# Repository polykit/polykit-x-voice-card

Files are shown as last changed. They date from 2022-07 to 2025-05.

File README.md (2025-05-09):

# Polykit-X Voice Card

This repository contains schematics and Kicad PCB layout for a voice card with pole-mixing multimode filter. Multiple cards like this are typically used in a polyphonic synthesizer. It can also be used in a monophonic setup. There is only minimal additional circuitry like some pots, input jacks and voltage regulators needed.

Voice card specs:

- Single oscillator with saw, triangle and pulse output
- Multiple VCAs to blend between different input signals, a main VCA for the envelope and a panning VCA for stereo output
- An additional external input that can be mixed in, eg. a noise signal
- One envelope generator for the VCA. It can modulate filter frequency and resonance, also with an inverted signal
- A pole-mixing multimode filter with 8 filter responses:
    - 4P LP
    - 2P LP
    - 4P HP
    - 2P HP
    - 4P BP
    - 2P BP
    - 3P AP + 1P LP
    - 4P N
- There are multiple options two switch and blend between different signals and filter responses
- PWM, FM and synchronization inputs

Video playlist on its functionality and design process: https://www.youtube.com/watch?v=2grRbG7IwDw&list=PLUKLEU8jmlbHH4_13YZM0MI6ez4gYQPfy

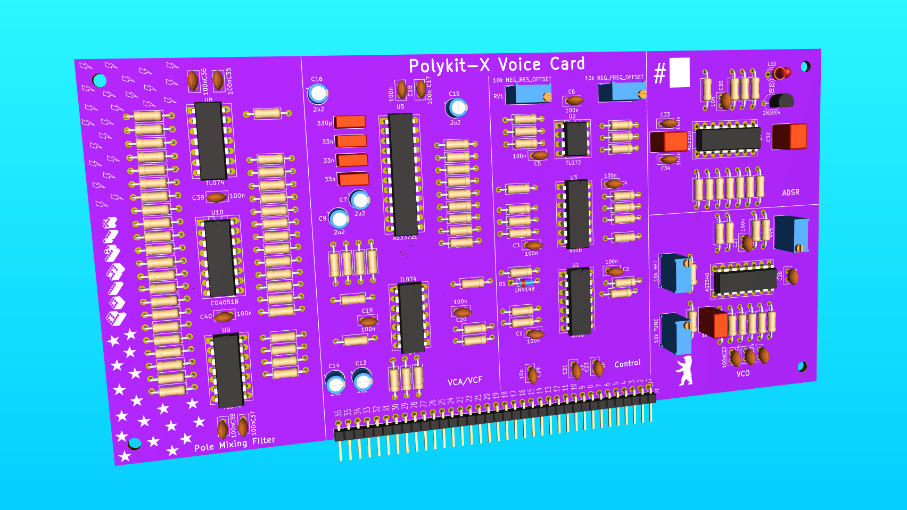
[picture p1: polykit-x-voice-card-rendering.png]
Polykit-X Voice Card Rendering


## Printed Circuit Boards

Geber files for PCB production [can be downloaded here](plots/).

## Pinout

| Pin # | Description | Short | Voltage Range | Type | Direction | Note |
|---|---|---|---|---|---|---|
| 1 | Ground | GND | | | |
| 2 | +12V | +12V | | | |
| 3 | -12V | -12V | | | |
| 4 | +5V | +5V | | | |
| 5 | -5V | -5V | | | |
| 6 | Pitch control | PITCH | ±5V | CV | | 1
| 7 | PWM | PWM | 0V to 5V | CV | |
| 8 | FM | FM | | Signal | |
| 9 | Soft sync | SSYNC | | Signal | |
| 10 | Hard sync | HSYNC | | Signal | |
| 11 | Envelope Attack | ADSR_A | 0V to -5V | CV | |
| 12 | Envelope Decay | ADSR_D | 0V to -5V | CV | |
| 13 | Envelope Sustain | ADSR_S | 0V to 5V | CV | |
| 14 | Envelope Release | ADSR_R | 0V to -5V | CV | |
| 15 | Envelope Trigger | TRIG | 0V/5V | Trig | |
| 16 | Envelope Gate | GATE | 0V/5V | Gate | |
| 17 | Envelope Output | ADSR_OUT | 0V to 5V | CV | |
| 18 | Enable saw signal | SAW_ON | 0V/5V | Switch | |
| 19 | Enable triangle sig. | TRIANGLE_ON | 0V/5V | Switch | |
| 20 | Enable ext. signal | EXTERNAL_ON | 0V/5V | Switch | |
| 21 | Neg. freq. by ADSR | FREQ_ADSR_NEQ | 0V/5V | Switch | |
| 22 | Freq. by ADSR | FREQ_ADSR | 0V/5V | Switch | |
| 23 | Res. by ADSR | RES_ADSR | 0V/5V | Switch | |
| 24 | Neg. res. by ADSR | REF_ADSR_NEQ  | 0V/5V | Switch | |
| 25 | Input level 1 | LVL1 | 0V to 5V | CV | |
| 26 | Input level 2 | LVL2 | 0V to 5V | CV | |
| 27 | VCA | VCA_CV | 0V to 5V | CV | |
| 28 | Output panning | PAN_CV | -2V to 2V | CV | |
| 29 | External input | EXTERNAL_IN | | Signal | |
| 30 | Freq. control | FREQ_CV | 0V to 5V | CV | |
| 31 | Res. control | RES_CV | 0V to 5V | CV | |
| 32 | Filter mode A | FILTER_MODE_A | 0V/5V | Switch | |
| 33 | Filter mode B | FILTER_MODE_B | 0V/5V | Switch | |
| 34 | Filter mode C | FILTER_MODE_C | 0V/5V | Switch | |
| 35 | Output left | OUT_L | | Signal | | 2
| 36 | Output right | OUT_R | | Signal | | 2

Note 1: A 100k ohm resistor on pitch CV input is needed. Multiple CV sources can be added by using multiple resistors in parallel

Note 2: Max. output volume can be adjusted by changing R32/R33

## Filter modes

| # | C B A | Filter response |
|---|---|---|
| 0 | 0 0 0 | 4P LP |
| 1 | 0 0 1 | 2P LP |
| 2 | 0 1 0 | 4P HP |
| 3 | 0 1 1 | 2P HP |
| 4 | 1 0 0 | 4P BP |
| 5 | 1 0 1 | 2P BP |
| 6 | 1 1 0 | 3P AP + 1P LP |
| 7 | 1 1 1 | 4P N |

Select filter mode on pins 32-34

0=GND, 1=5V

## Tuning Procedure

### VCO

You need a control voltage 1V/octave source like a keyboard or two fixed, precise voltages in order to tune the VCO. Also a tuning device or a mobile tuning app is needed.

RV3 (TUNE) is for trimming the overall tune, RV5 (SCALE) is for adjusting the distance between two notes.

Take two notes that are one octave apart, eg. C3 and C4. play the first note and trim RV3 to that note.

Now go back and forth between both notes and adjust RV5 so that the correct distance between them gets closer. The first note will drift away while doing this so go back to it by adjusting RV3 again from time to time. Repeat this until both notes are perfectly in tune.

RV4 (HFT) is for trimming the higher frequencies if neccessary.

## BOM

|Reference |Qnty|Value |Description |
|---|----|---|---|
|C1, C2, C3, C4, C5, C6, C17, C18, C19, C20, C22, C27, C28, C33, C34, C35, C36, C37, C38, C39, C40 |21  |100n |Unpolarized capacitor |
|C7, C9, C13, C14, C15, C16 |6 |2,2uF |Polarized capacitor |
|C8, |1 |330p |Unpolarized capacitor, film or mylar |
|C10, C11, C12 |3 |33n |Unpolarized capacitor, film or mylar |
|C21, C23 |2 |1n |Unpolarized capacitor |
|C24, C25, C29, C30 |4 |10n |Unpolarized capacitor |
|C26 |1 |1n* |Unpolarized capacitor, *polypropylene or similar |
|C31 |1 |10n* |Unpolarized capacitor, *polypropylene or similar |
|C32 |1 |33n* |Unpolarized capacitor, *polypropylene or similar |
|D1 |1 |1N4148 |100V 0.15A standard switching diode, DO-35 |
|D2 |1 |LED |3mm |
|J1 |1 |Conn_01x36 | Pin header 2.54mm 1x36pin 90 degree angle
|Q1 |1 |2N3904 | NPN Transistor, TO-92 |
|R1, R3, R4, R43, R44 |5 |1M |Resistor |
|R2, R28, R29, R38, R42 |4 |470k |Resistor |
|R5, R6, R7, R21, R22, R24, R25, R54, R55, R56, R60, R63, R68, R73, R74, R75, R76, R93, R101, R102, R103 |21  |10k |Resistor |
|R8, R9, R10, R11, R12, R13, R14, R15, R18, R19, R20, R69, R70, R71 |14  |100k |Resistor |
|R16, R17, R23 |3 |20k |Resistor |
|R26, R27, R41, R72 |4 |68k |Resistor |
|R30, R31, R34, R35, R37, R64, R65, R66, R67 |9 |1k |Resistor |
|R32, R33, R36, R62 |4 |33k |Resistor |
|R39, R40 |2 |22k |Resistor |
|R45 |1 |330k |Resistor |
|R46 |1 |1M5 |Resistor |
|R47, R48, R57, R58, R59 |5 |470 |Resistor |
|R49 |1 |24k |Resistor |
|R50 |1 |5k6 |Resistor |
|R51 |1 |1k8 |Resistor |
|R52 |1 |10M |Resistor |
|R53 |1 |47k |Resistor |
|R61 |1 |680 |Resistor |
|R77, R79, R80, R81, R82, R86, R87, R89, R90, R91, R92, R96 |12  |30k |Resistor |
|R78, R88, R97, R98, R99, R100 |6 |15k |Resistor |
|R83, R85, R95 |3 |7k5 |Resistor |
|R84, R94 |2 |4k99 |Resistor |
|R104 |1 |4k7 |Resistor |
|RV1 |1 |10k NEG_RES_OFFSET |Trim-potentiometer |
|RV2 |1 |10k NEG_FREQ_OFFSET|Trim-potentiometer |
|RV3 |1 |10k TUNE |Trim-potentiometer |
|RV4 |1 |10k HFT |Trim-potentiometer |
|RV5 |1 |10k SCALE |Trim-potentiometer |
|U1, U3 |2 |4016 |Quad Analog Switches |
|U2 |1 |TL072 |Dual Low-Noise JFET-Input Operational Amplifiers, DIP-8/SOIC-8 |
|U4, U8, U9 |3 |TL074 |Quad Low-Noise JFET-Input Operational Amplifiers, DIP-14/SOIC-14 |
|U5 |1 |AS3372E |4-pole VCF, dual channel input mixer, VCA, panning VCA |
|U6 |1 |AS3340 |Voltage Controlled Oscillator (VCO), DIP-16/SOIC-16 |
|U7 |1 |AS3310 |ADSR Voltage Controlled Envelope Generator, DIP-16/SOIC-16 |
|U10 |1 |CD4051B |CMOS single 8-channel analog multiplexer demultiplexer, TSSOP-16/DIP-16/SOIC-16 |

## References

Article on Pole Mixing Filters: https://electricdruid.net/multimode-filters-part-2-pole-mixing-filters

Oberheim Matrix-12 Service Manual: https://archive.org/details/oberheim_MATRIX-12_SERVICE_MANUAL

Oberheim Xpander Service Manual: https://archive.org/details/oberheim_XPANDER_SERVICE_MANUAL

Sequential Prophet T8 Service Manual: https://archive.org/details/sm_SCI_T8_Service_Manual_Complete_sm

AS3372E Datasheet: https://www.ericasynths.lv/media/AS3372E.pdf

AS3310 Datasheet: https://www.alfarzpp.lv/eng/sc/AS3310.pdf

AS3340 Datasheet: https://www.alfarzpp.lv/eng/sc/AS3340.pdf

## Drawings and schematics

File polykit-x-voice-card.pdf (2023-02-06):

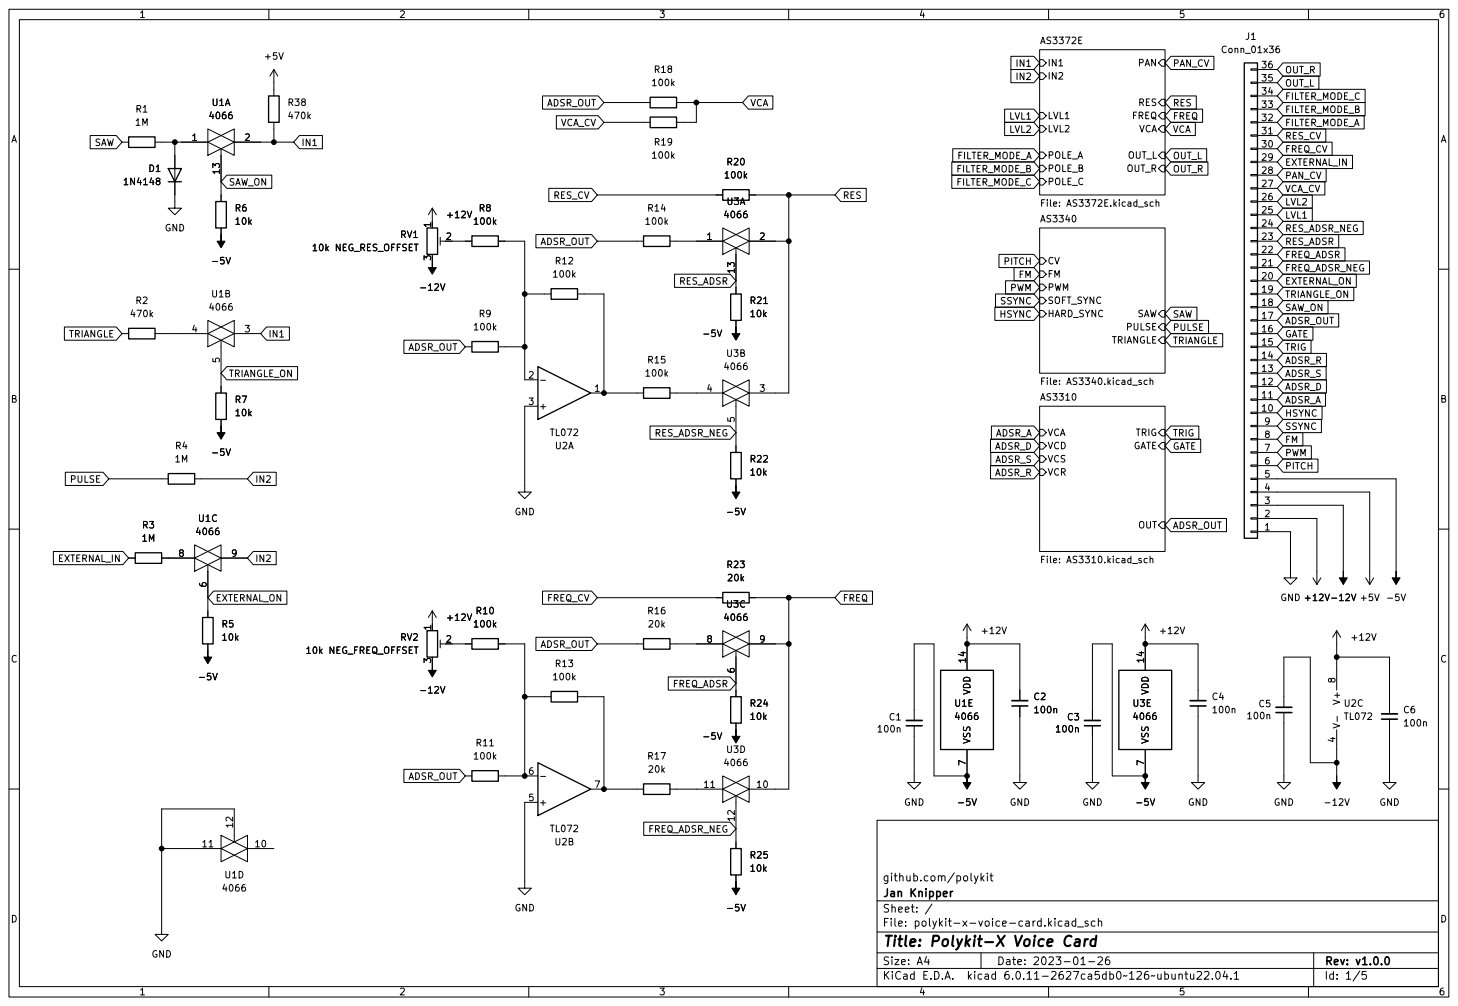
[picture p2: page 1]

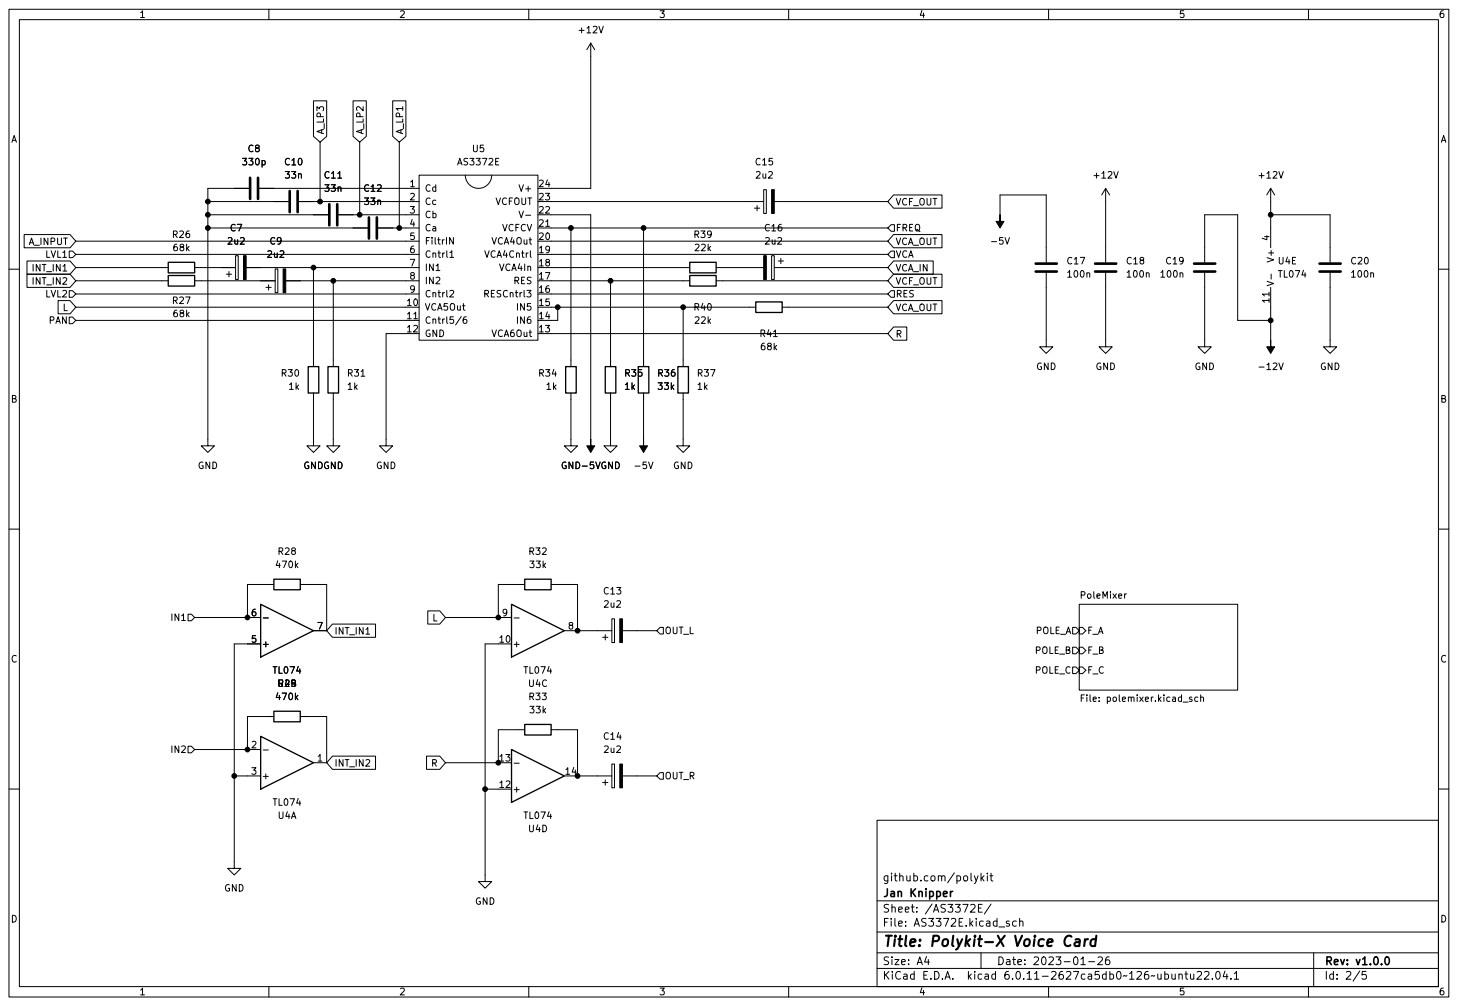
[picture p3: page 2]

PoleMixer File: polemixer.kicad_sch GND

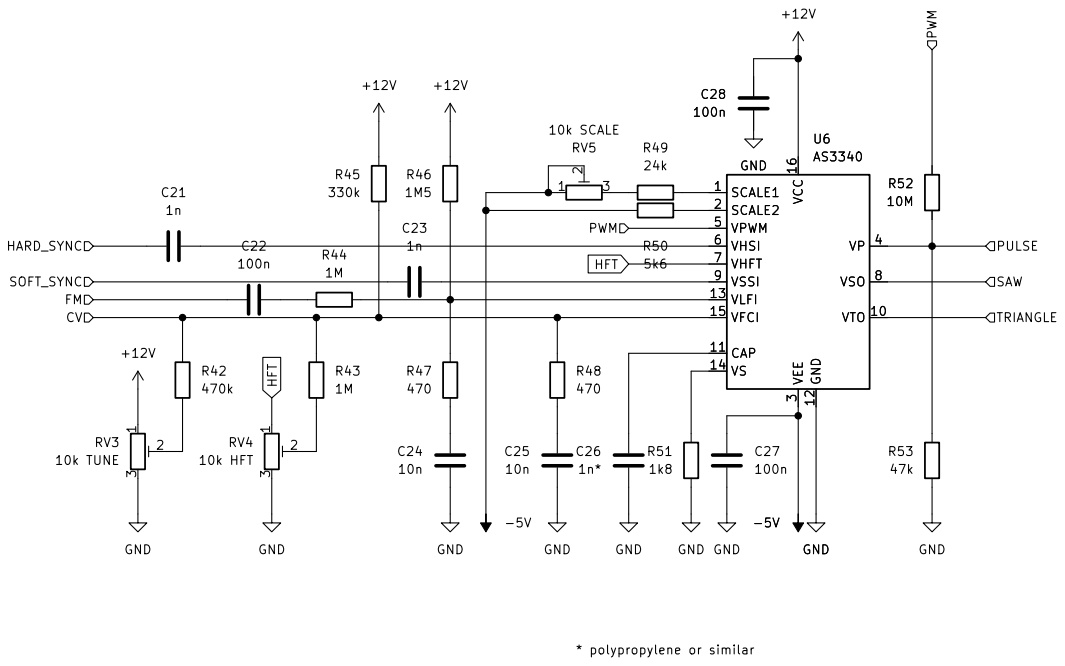
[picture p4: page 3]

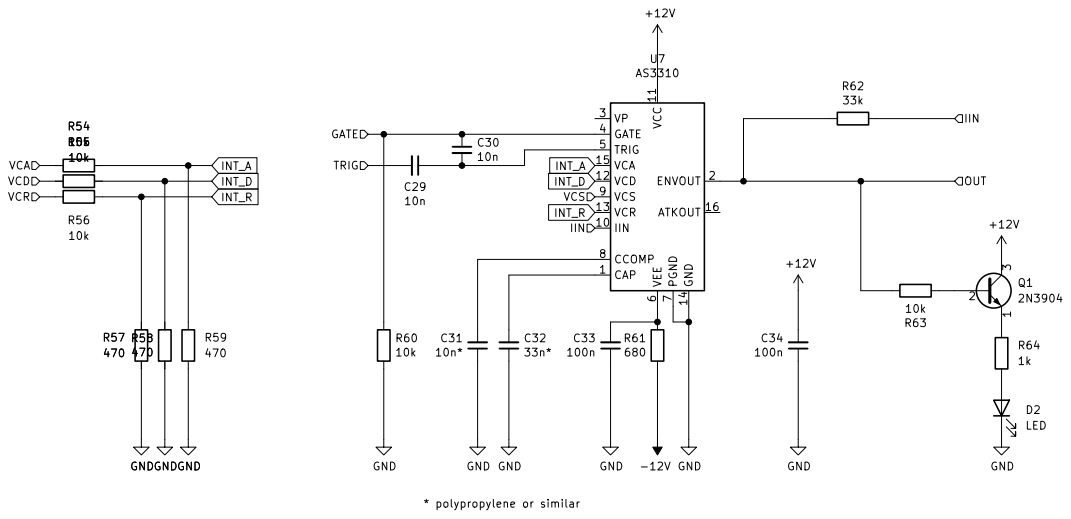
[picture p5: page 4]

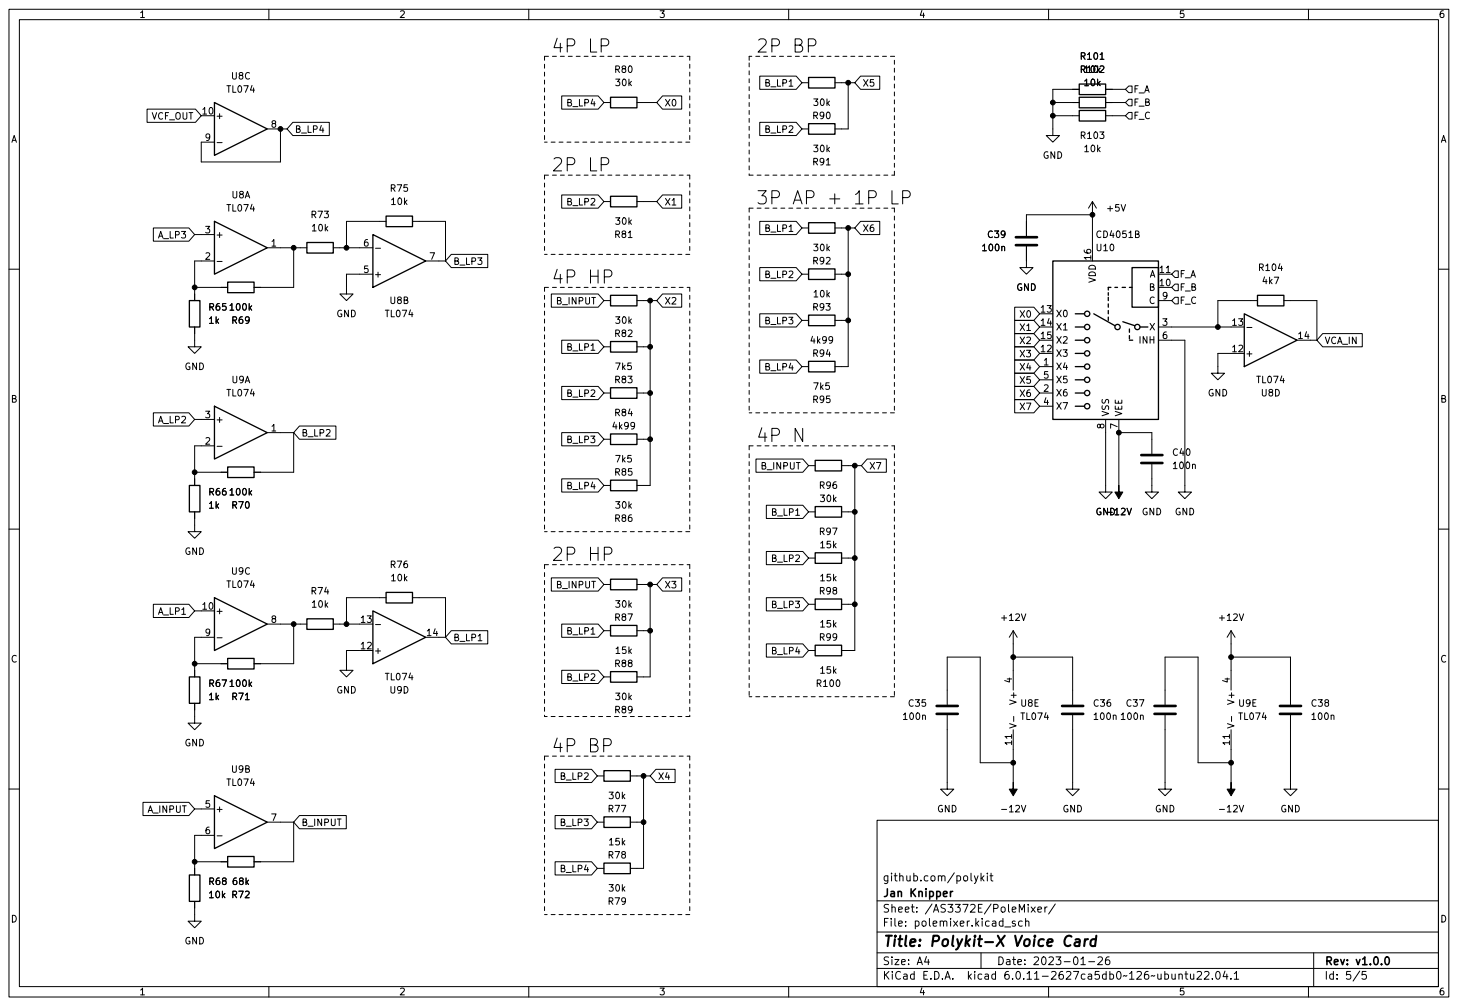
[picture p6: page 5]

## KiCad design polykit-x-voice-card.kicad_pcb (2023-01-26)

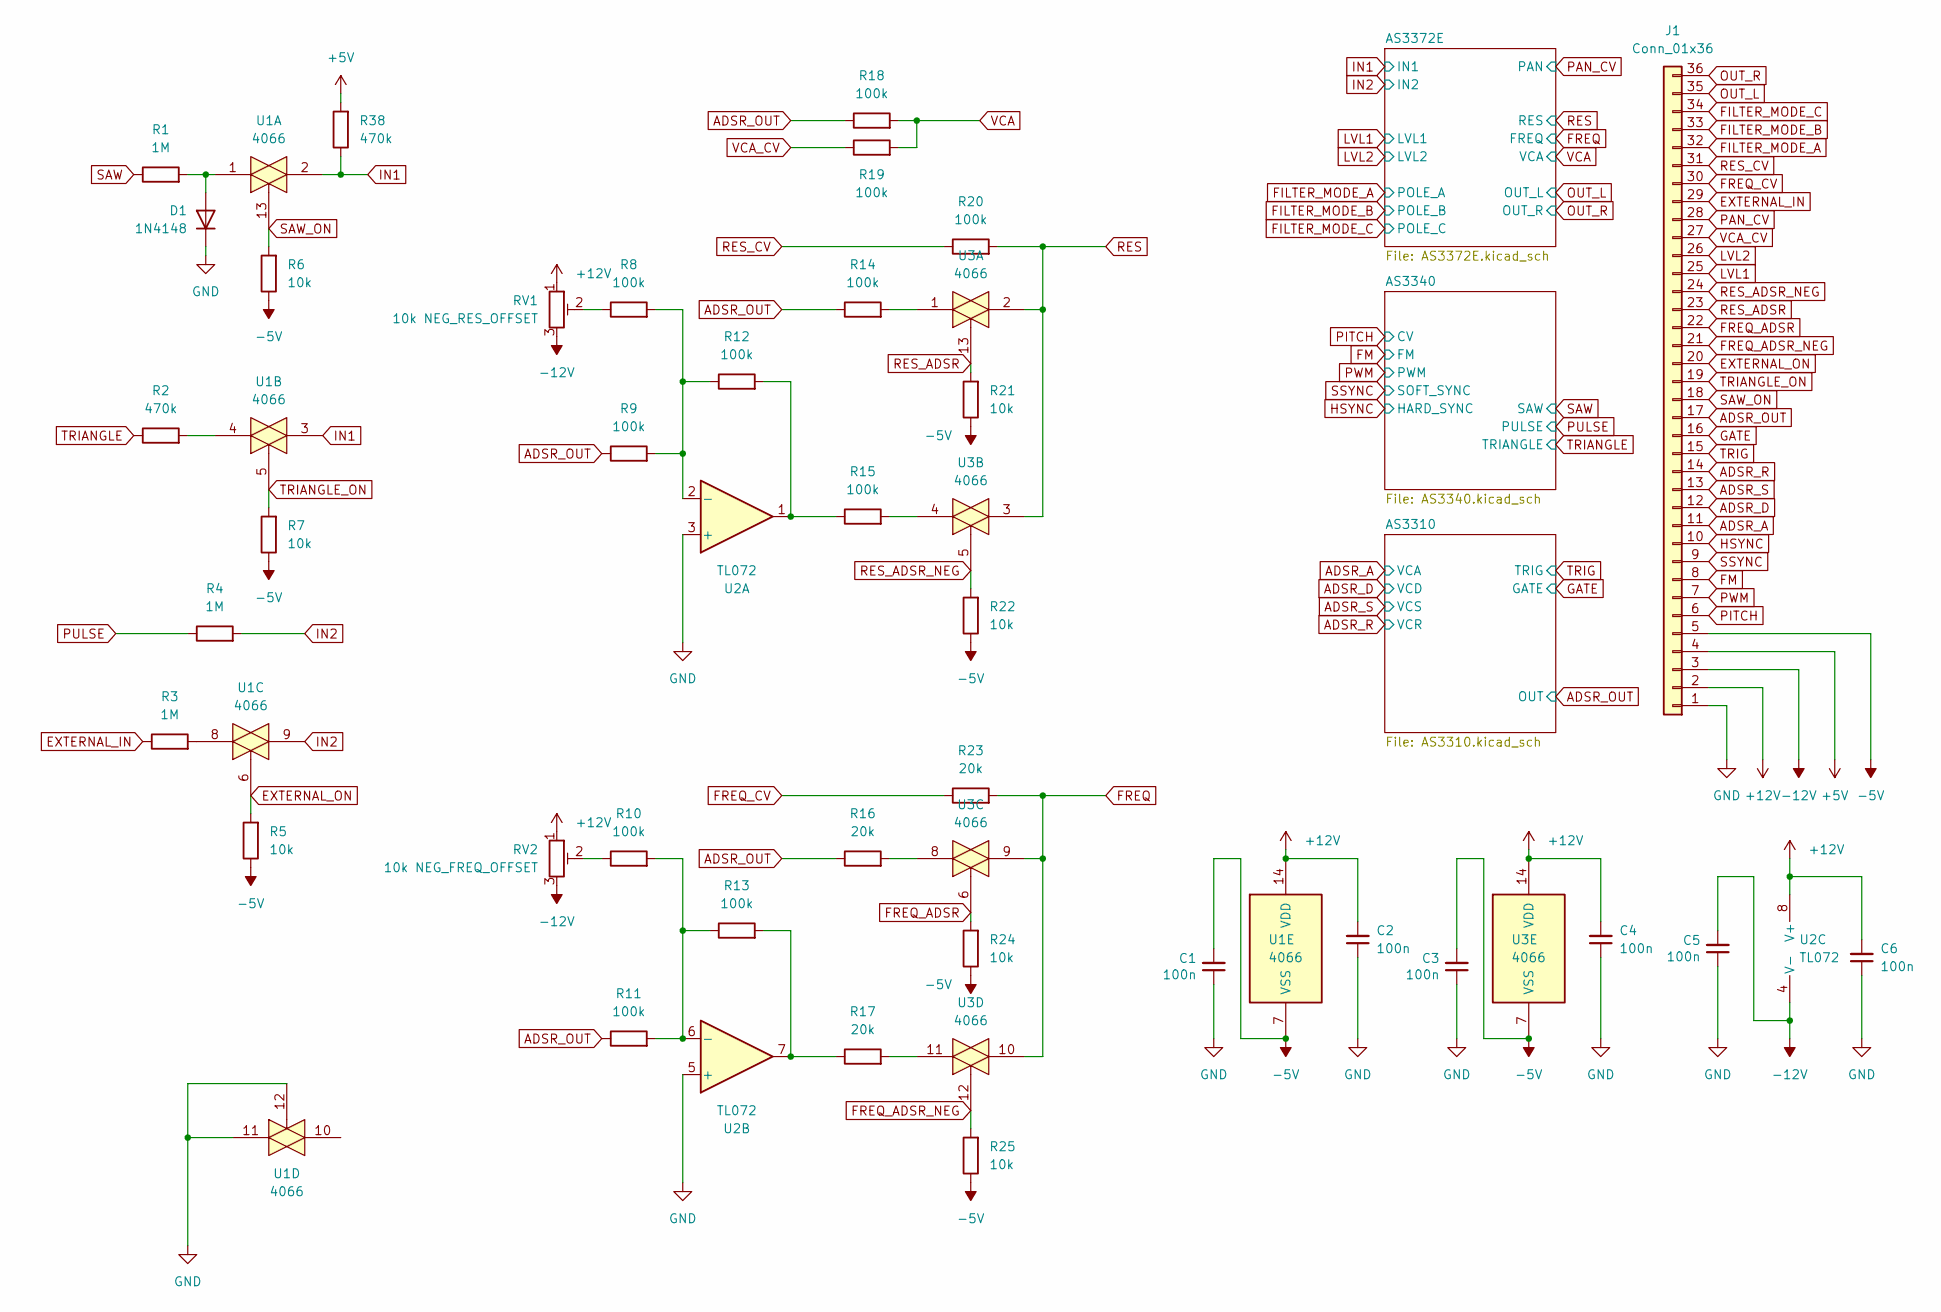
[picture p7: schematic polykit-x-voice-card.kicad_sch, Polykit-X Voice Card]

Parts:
C1, C2, C3, C4, C5, C6: 100n; C_Disc_D5.0mm_W2.5mm_P2.50mm
D1: 1N4148; D_DO-35_SOD27_P7.62mm_Horizontal
J1: Conn_01x36; PinHeader_1x36_P2.54mm_Horizontal
R1, R3, R4: 1M; R_Axial_DIN0207_L6.3mm_D2.5mm_P10.16mm_Horizontal
R2, R38: 470k; R_Axial_DIN0207_L6.3mm_D2.5mm_P10.16mm_Horizontal
R5, R6, R7, R21, R22, R24, R25: 10k; R_Axial_DIN0207_L6.3mm_D2.5mm_P10.16mm_Horizontal
R8, R9, R10, R11, R12, R13, R14, R15, R18, R19, R20: 100k; R_Axial_DIN0207_L6.3mm_D2.5mm_P10.16mm_Horizontal
R16, R17, R23: 20k; R_Axial_DIN0207_L6.3mm_D2.5mm_P10.16mm_Horizontal
RV1: 10k NEG_RES_OFFSET; Potentiometer_Bourns_3296W_Vertical
RV2: 10k NEG_FREQ_OFFSET; Potentiometer_Bourns_3296W_Vertical
U1, U3: 4066; DIP-14_W7.62mm_Socket_LongPads
U2: TL072; DIP-8_W7.62mm_Socket_LongPads

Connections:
+5V: J1.4, R38.2; also elsewhere on the board
+12V: C2.2, C4.2, C6.2, J1.2, RV1.1, RV2.1, U1.14 (VDD), U2.8 (V+), U3.14 (VDD); also elsewhere on the board
-5V: C1.2, C3.2, J1.5, R5.1, R6.1, R7.1, R21.1, R22.1, R24.1, R25.1, U1.7 (VSS), U3.7 (VSS); also elsewhere on the board
-12V: C5.2, J1.3, RV1.3, RV2.3, U2.4 (V-); also elsewhere on the board
ADSR_A: J1.11; also elsewhere on the board
ADSR_D: J1.12; also elsewhere on the board
ADSR_OUT: J1.17, R9.1, R11.1, R14.1, R16.1, R18.1; also elsewhere on the board
ADSR_R: J1.14; also elsewhere on the board
ADSR_S: J1.13; also elsewhere on the board
EXTERNAL_IN: J1.29, R3.1
EXTERNAL_ON: J1.20, R5.2, U1.6
FILTER_MODE_A: J1.32; also elsewhere on the board
FILTER_MODE_B: J1.33; also elsewhere on the board
FILTER_MODE_C: J1.34; also elsewhere on the board
FM: J1.8; also elsewhere on the board
FREQ: R23.2, U3.9, U3.10; also elsewhere on the board
FREQ_ADSR: J1.22, R24.2, U3.6
FREQ_ADSR_NEG: J1.21, R25.2, U3.12
FREQ_CV: J1.30, R23.1
GATE: J1.16; also elsewhere on the board
GND: C1.1, C2.1, C3.1, C4.1, C5.1, C6.1, D1.1 (K), J1.1, U1.11, U1.12, U2.3 (+), U2.5 (+); also elsewhere on the board
HSYNC: J1.10; also elsewhere on the board
IN1: R38.1, U1.2, U1.3; also elsewhere on the board
IN2: R4.2, U1.9; also elsewhere on the board
LVL1: J1.25; also elsewhere on the board
LVL2: J1.26; also elsewhere on the board
unnamed: D1.2 (A), R1.2, U1.1
unnamed: R2.2, U1.4
unnamed: R3.2, U1.8
unnamed: R8.1, RV1.2
unnamed: R10.1, RV2.2
unnamed: R10.2, R11.2, R13.1, U2.6 (-)
unnamed: R8.2, R9.2, R12.1, U2.2 (-)
unnamed: R12.2, R15.1, U2.1
unnamed: R13.2, R17.1, U2.7
unnamed: R14.2, U3.1
unnamed: R15.2, U3.4
unnamed: R16.2, U3.8
unnamed: R17.2, U3.11
OUT_L: J1.35; also elsewhere on the board
OUT_R: J1.36; also elsewhere on the board
PAN_CV: J1.28; also elsewhere on the board
PITCH: J1.6; also elsewhere on the board
PULSE: R4.1; also elsewhere on the board
PWM: J1.7; also elsewhere on the board
RES: R20.2, U3.2, U3.3; also elsewhere on the board
RES_ADSR: J1.23, R21.2, U3.13
RES_ADSR_NEG: J1.24, R22.2, U3.5
RES_CV: J1.31, R20.1
SAW: R1.1; also elsewhere on the board
SAW_ON: J1.18, R6.2, U1.13
SSYNC: J1.9; also elsewhere on the board
TRIANGLE: R2.1; also elsewhere on the board
TRIANGLE_ON: J1.19, R7.2, U1.5
TRIG: J1.15; also elsewhere on the board
VCA: R18.2, R19.2; also elsewhere on the board
VCA_CV: J1.27, R19.1

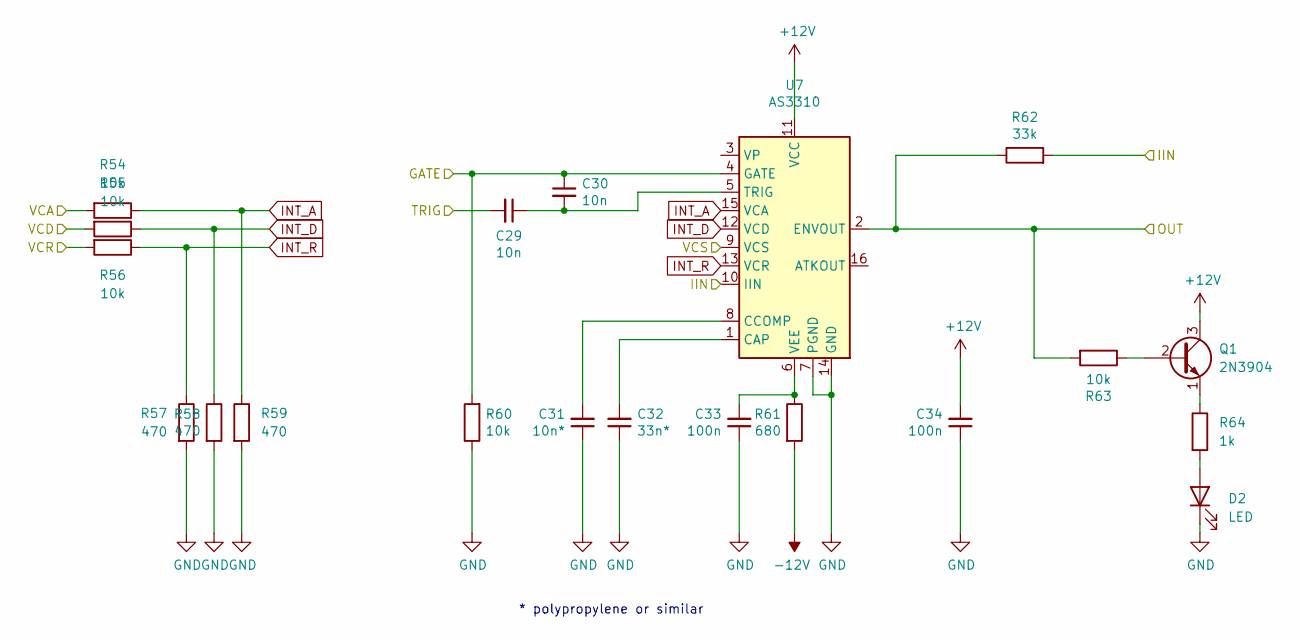
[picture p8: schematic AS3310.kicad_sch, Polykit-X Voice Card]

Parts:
C29, C30: 10n; C_Disc_D5.0mm_W2.5mm_P2.50mm
C31: 10n*; C_Rect_L7.2mm_W5.5mm_P5.00mm_FKS2_FKP2_MKS2_MKP2
C32: 33n*; C_Rect_L7.2mm_W5.5mm_P5.00mm_FKS2_FKP2_MKS2_MKP2
C33, C34: 100n; C_Disc_D5.0mm_W2.5mm_P2.50mm
D2: LED; LED_D3.0mm
Q1: 2N3904; TO-92_Inline_Wide
R54, R55, R56, R60, R63: 10k; R_Axial_DIN0207_L6.3mm_D2.5mm_P10.16mm_Horizontal
R57, R58, R59: 470; R_Axial_DIN0207_L6.3mm_D2.5mm_P10.16mm_Horizontal
R61: 680; R_Axial_DIN0207_L6.3mm_D2.5mm_P10.16mm_Horizontal
R62: 33k; R_Axial_DIN0207_L6.3mm_D2.5mm_P10.16mm_Horizontal
R64: 1k; R_Axial_DIN0207_L6.3mm_D2.5mm_P10.16mm_Horizontal
U7: AS3310; DIP-16_W7.62mm_Socket_LongPads

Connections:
+12V: C34.2, Q1.3 (C), U7.11 (VCC); also elsewhere on the board
-12V: R61.2; also elsewhere on the board
/AS3310/IIN: R62.2, U7.10 (IIN)
ADSR_A: R54.2; also elsewhere on the board
ADSR_D: R55.2; also elsewhere on the board
ADSR_OUT: R62.1, R63.2, U7.2 (ENVOUT); also elsewhere on the board
ADSR_R: R56.2; also elsewhere on the board
ADSR_S: U7.9 (VCS); also elsewhere on the board
GATE: C30.1, R60.2, U7.4 (GATE); also elsewhere on the board
GND: C31.1, C32.1, C33.1, C34.1, D2.1 (K), R57.2, R58.2, R59.2, R60.1, U7.7 (PGND), U7.14 (GND); also elsewhere on the board
INT_A: R54.1, R59.1, U7.15 (VCA)
INT_D: R55.1, R58.1, U7.12 (VCD)
INT_R: R56.1, R57.1, U7.13 (VCR)
unnamed: C29.1, C30.2, U7.5 (TRIG)
unnamed: C31.2, U7.8 (CCOMP)
unnamed: C32.2, U7.1 (CAP)
unnamed: C33.2, R61.1, U7.6 (VEE)
unnamed: D2.2 (A), R64.2
unnamed: Q1.1 (E), R64.1
unnamed: Q1.2 (B), R63.1
TRIG: C29.2; also elsewhere on the board

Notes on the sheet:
* polypropylene or similar

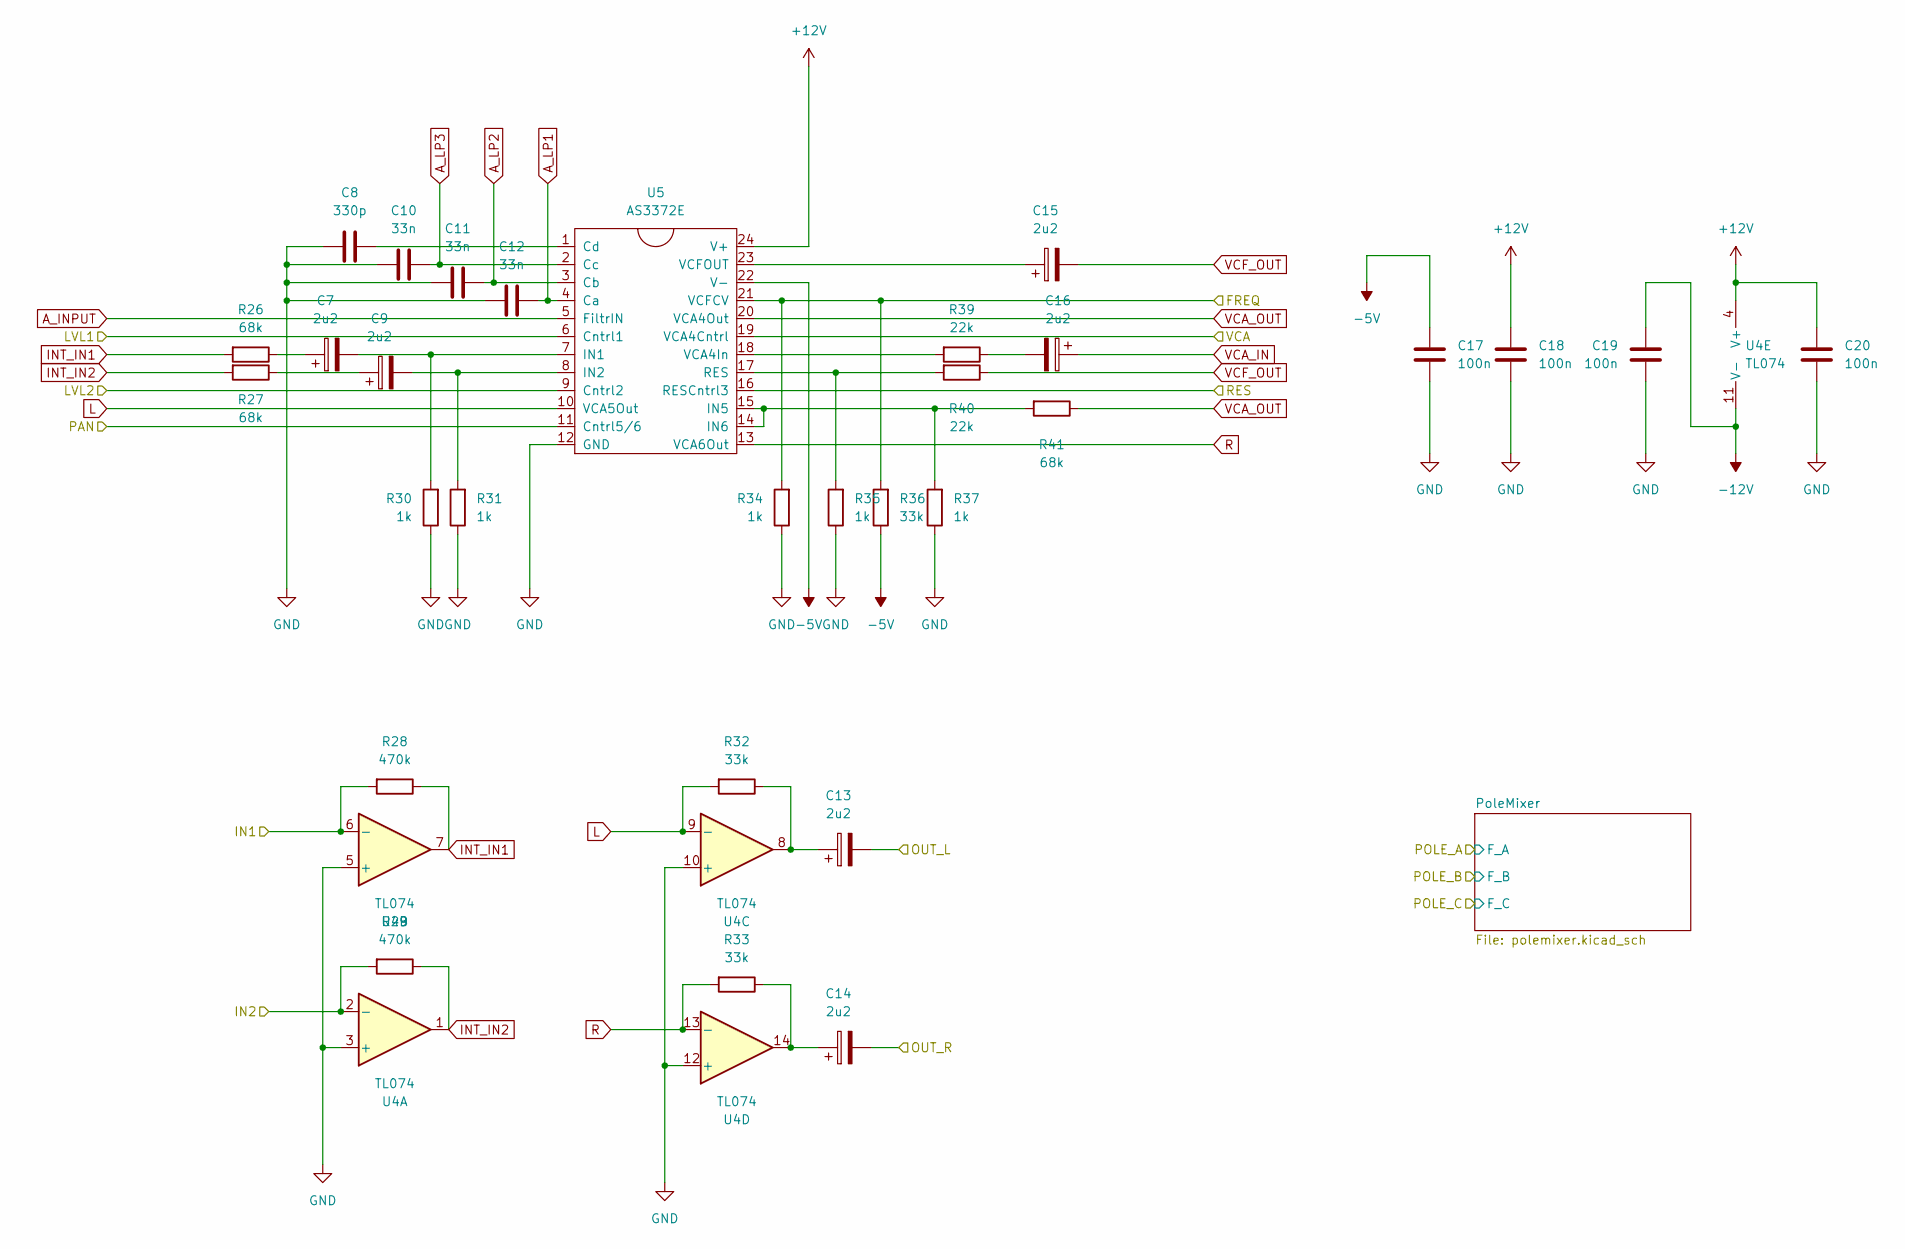
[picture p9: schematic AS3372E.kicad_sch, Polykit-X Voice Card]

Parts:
C7, C9, C13, C14, C15, C16: 2u2; CP_Radial_D5.0mm_P2.00mm
C8: 330p; C_Rect_L7.2mm_W3.0mm_P5.00mm_FKS2_FKP2_MKS2_MKP2
C10, C11, C12: 33n; C_Rect_L7.2mm_W3.0mm_P5.00mm_FKS2_FKP2_MKS2_MKP2
C17, C18, C19, C20: 100n; C_Disc_D5.0mm_W2.5mm_P2.50mm
R26, R27, R41: 68k; R_Axial_DIN0207_L6.3mm_D2.5mm_P10.16mm_Horizontal
R28, R29: 470k; R_Axial_DIN0207_L6.3mm_D2.5mm_P10.16mm_Horizontal
R30, R31, R34, R35, R37: 1k; R_Axial_DIN0207_L6.3mm_D2.5mm_P10.16mm_Horizontal
R32, R33, R36: 33k; R_Axial_DIN0207_L6.3mm_D2.5mm_P10.16mm_Horizontal
R39, R40: 22k; R_Axial_DIN0207_L6.3mm_D2.5mm_P10.16mm_Horizontal
U4: TL074; DIP-14_W7.62mm_Socket_LongPads
U5: AS3372E; DIP-24_W7.62mm_Socket_LongPads

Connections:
+12V: C18.1, C20.2, U4.4 (V+), U5.24 (V+); also elsewhere on the board
-5V: C17.1, R36.1, U5.22 (V-); also elsewhere on the board
-12V: C19.2, U4.11 (V-); also elsewhere on the board
A_INPUT: U5.5 (FiltrIN); also elsewhere on the board
A_LP1: C12.2, U5.4 (Ca); also elsewhere on the board
A_LP2: C11.2, U5.3 (Cb); also elsewhere on the board
A_LP3: C10.2, U5.2 (Cc); also elsewhere on the board
FREQ: R34.2, R36.2, U5.21 (VCFCV); also elsewhere on the board
GND: C8.1, C10.1, C11.1, C12.1, C17.2, C18.2, C19.1, C20.1, R30.1, R31.1, R34.1, R35.1, R37.1, U4.3 (+), U4.5 (+), U4.10 (+), U4.12 (+), U5.12 (GND); also elsewhere on the board
IN1: R28.2, U4.6 (-); also elsewhere on the board
IN2: R29.2, U4.2 (-); also elsewhere on the board
INT_IN1: R26.2, R28.1, U4.7
INT_IN2: R27.2, R29.1, U4.1
L: R32.2, U4.9 (-), U5.10 (VCA5Out)
LVL1: U5.6 (Cntrl1); also elsewhere on the board
LVL2: U5.9 (Cntrl2); also elsewhere on the board
unnamed: C7.1, R26.1
unnamed: C7.2, R30.2, U5.7 (IN1)
unnamed: C8.2, U5.1 (Cd)
unnamed: C9.1, R27.1
unnamed: C9.2, R31.2, U5.8 (IN2)
unnamed: C13.1, R32.1, U4.8
unnamed: C14.1, R33.1, U4.14
unnamed: C15.1, U5.23 (VCFOUT)
unnamed: C16.2, R39.1
unnamed: R35.2, R40.2, U5.17 (RES)
unnamed: R37.2, R41.2, U5.14 (IN6), U5.15 (IN5)
unnamed: R39.2, U5.18 (VCA4In)
OUT_L: C13.2; also elsewhere on the board
OUT_R: C14.2; also elsewhere on the board
PAN_CV: U5.11 (Cntrl5/6); also elsewhere on the board
R: R33.2, U4.13 (-), U5.13 (VCA6Out)
RES: U5.16 (RESCntrl3); also elsewhere on the board
VCA: U5.19 (VCA4Cntrl); also elsewhere on the board
VCA_IN: C16.1; also elsewhere on the board
VCA_OUT: R41.1, U5.20 (VCA4Out)
VCF_OUT: C15.2, R40.1; also elsewhere on the board

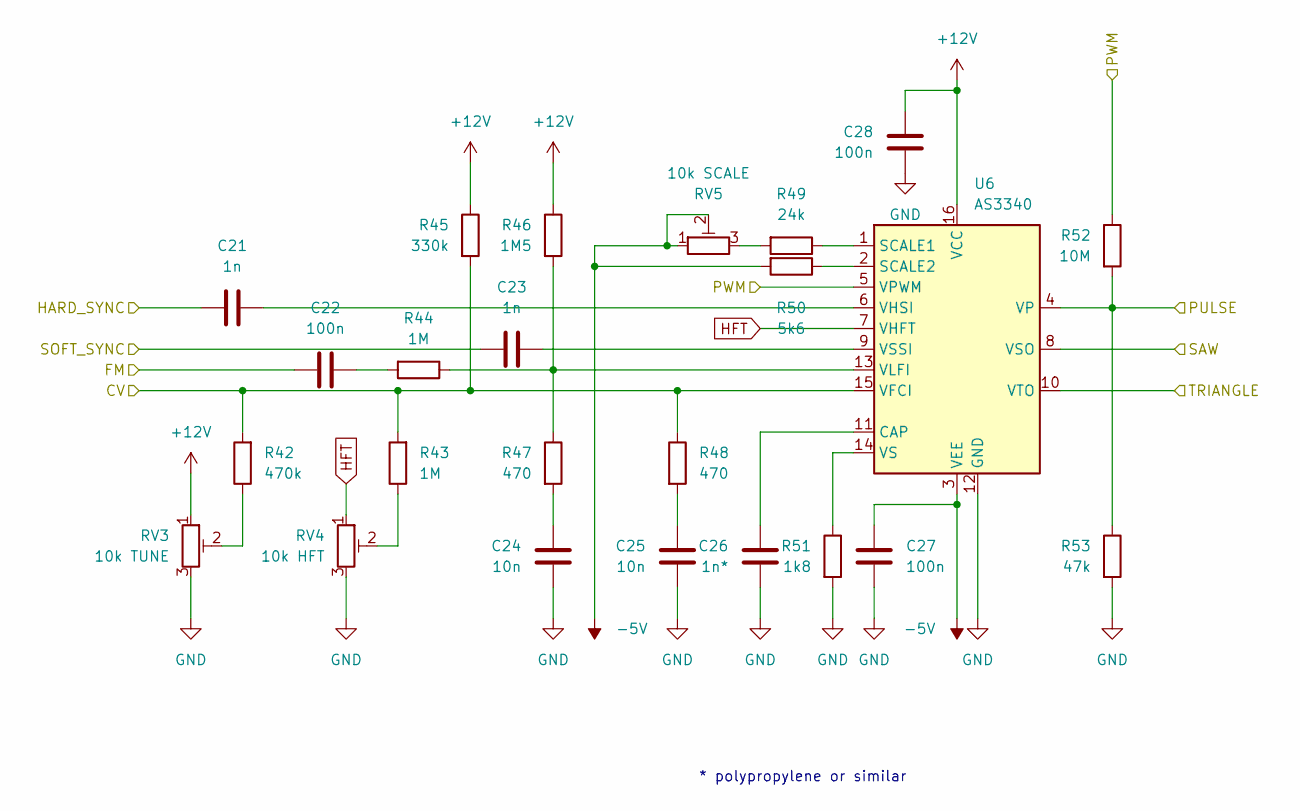
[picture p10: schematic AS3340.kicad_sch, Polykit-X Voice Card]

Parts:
C21, C23: 1n; C_Disc_D5.0mm_W2.5mm_P2.50mm
C22, C27, C28: 100n; C_Disc_D5.0mm_W2.5mm_P2.50mm
C24, C25: 10n; C_Disc_D5.0mm_W2.5mm_P2.50mm
C26: 1n*; C_Rect_L7.2mm_W4.5mm_P5.00mm_FKS2_FKP2_MKS2_MKP2
R42: 470k; R_Axial_DIN0207_L6.3mm_D2.5mm_P10.16mm_Horizontal
R43, R44: 1M; R_Axial_DIN0207_L6.3mm_D2.5mm_P10.16mm_Horizontal
R45: 330k; R_Axial_DIN0207_L6.3mm_D2.5mm_P10.16mm_Horizontal
R46: 1M5; R_Axial_DIN0207_L6.3mm_D2.5mm_P10.16mm_Horizontal
R47, R48: 470; R_Axial_DIN0207_L6.3mm_D2.5mm_P10.16mm_Horizontal
R49: 24k; R_Axial_DIN0207_L6.3mm_D2.5mm_P10.16mm_Horizontal
R50: 5k6; R_Axial_DIN0207_L6.3mm_D2.5mm_P10.16mm_Horizontal
R51: 1k8; R_Axial_DIN0207_L6.3mm_D2.5mm_P10.16mm_Horizontal
R52: 10M; R_Axial_DIN0207_L6.3mm_D2.5mm_P10.16mm_Horizontal
R53: 47k; R_Axial_DIN0207_L6.3mm_D2.5mm_P10.16mm_Horizontal
RV3: 10k TUNE; Potentiometer_Bourns_3296W_Vertical
RV4: 10k HFT; Potentiometer_Bourns_3296W_Vertical
RV5: 10k SCALE; Potentiometer_Bourns_3296W_Vertical
U6: AS3340; DIP-16_W7.62mm_Socket_LongPads

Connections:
+12V: C28.1, R45.1, R46.1, RV3.1, U6.16 (VCC); also elsewhere on the board
-5V: C27.1, R50.2, RV5.1, RV5.2, U6.3 (VEE); also elsewhere on the board
FM: C22.2; also elsewhere on the board
GND: C24.2, C25.2, C26.2, C27.2, C28.2, R51.2, R53.2, RV3.3, RV4.3, U6.12 (GND); also elsewhere on the board
HFT: RV4.1, U6.7 (VHFT)
HSYNC: C21.1; also elsewhere on the board
unnamed: C21.2, U6.6 (VHSI)
unnamed: C22.1, R44.2
unnamed: C23.2, U6.9 (VSSI)
unnamed: C24.1, R47.2
unnamed: C25.1, R48.2
unnamed: C26.1, U6.11 (CAP)
unnamed: R42.1, RV3.2
unnamed: R43.1, RV4.2
unnamed: R44.1, R46.2, R47.1, U6.13 (VLFI)
unnamed: R49.1, U6.1 (SCALE1)
unnamed: R49.2, RV5.3
unnamed: R50.1, U6.2 (SCALE2)
unnamed: R51.1, U6.14 (VS)
PITCH: R42.2, R43.2, R45.2, R48.1, U6.15 (VFCI); also elsewhere on the board
PULSE: R52.2, R53.1, U6.4 (VP); also elsewhere on the board
PWM: R52.1, U6.5 (VPWM); also elsewhere on the board
SAW: U6.8 (VSO); also elsewhere on the board
SSYNC: C23.1; also elsewhere on the board
TRIANGLE: U6.10 (VTO); also elsewhere on the board

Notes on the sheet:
* polypropylene or similar

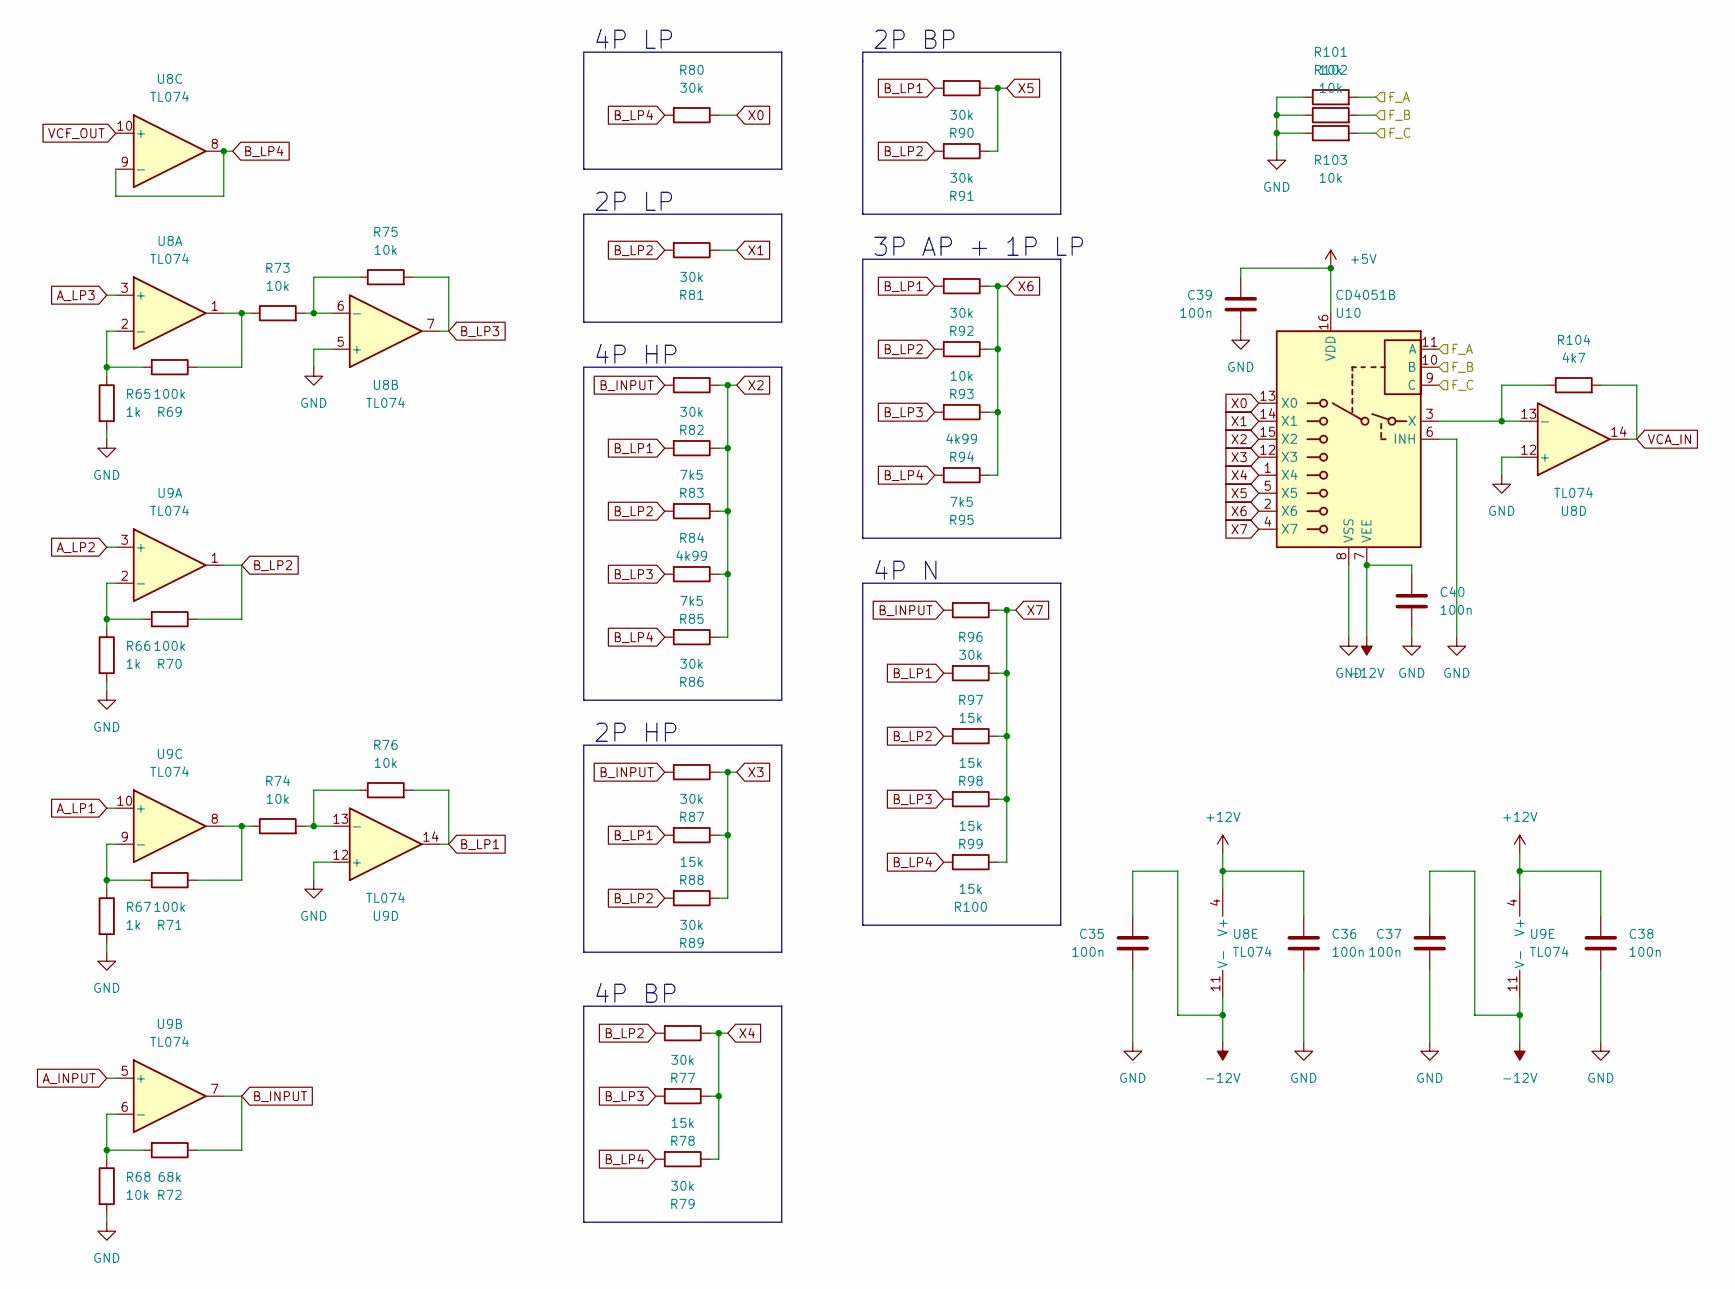
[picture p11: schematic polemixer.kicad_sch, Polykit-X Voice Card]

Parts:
C35, C36, C37, C38, C39, C40: 100n; C_Disc_D5.0mm_W2.5mm_P2.50mm
R65, R66, R67: 1k; R_Axial_DIN0207_L6.3mm_D2.5mm_P10.16mm_Horizontal
R68, R73, R74, R75, R76, R93, R101, R102, R103: 10k; R_Axial_DIN0207_L6.3mm_D2.5mm_P10.16mm_Horizontal
R69, R70, R71: 100k; R_Axial_DIN0207_L6.3mm_D2.5mm_P10.16mm_Horizontal
R72: 68k; R_Axial_DIN0207_L6.3mm_D2.5mm_P10.16mm_Horizontal
R77, R79, R80, R81, R82, R86, R87, R89, R90, R91, R92, R96: 30k; R_Axial_DIN0207_L6.3mm_D2.5mm_P10.16mm_Horizontal
R78, R88, R97, R98, R99, R100: 15k; R_Axial_DIN0207_L6.3mm_D2.5mm_P10.16mm_Horizontal
R83, R85, R95: 7k5; R_Axial_DIN0207_L6.3mm_D2.5mm_P10.16mm_Horizontal
R84, R94: 4k99; R_Axial_DIN0207_L6.3mm_D2.5mm_P10.16mm_Horizontal
R104: 4k7; R_Axial_DIN0207_L6.3mm_D2.5mm_P10.16mm_Horizontal
U8, U9: TL074; DIP-14_W7.62mm_Socket_LongPads
U10: CD4051B; DIP-16_W7.62mm_Socket_LongPads

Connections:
+5V: C39.2, U10.16 (VDD); also elsewhere on the board
+12V: C36.2, C38.2, U8.4 (V+), U9.4 (V+); also elsewhere on the board
-12V: C35.2, C37.2, C40.2, U8.11 (V-), U9.11 (V-), U10.7 (VEE); also elsewhere on the board
A_INPUT: U9.5 (+); also elsewhere on the board
A_LP1: U9.10 (+); also elsewhere on the board
A_LP2: U9.3 (+); also elsewhere on the board
A_LP3: U8.3 (+); also elsewhere on the board
B_INPUT: R72.1, R82.2, R87.2, R96.2, U9.7
B_LP1: R76.2, R83.2, R88.2, R90.2, R92.2, R97.2, U9.14
B_LP2: R70.1, R77.2, R81.2, R84.2, R89.2, R91.2, R93.2, R98.2, U9.1
B_LP3: R75.2, R78.2, R85.2, R94.2, R99.2, U8.7
B_LP4: R79.2, R80.2, R86.2, R95.2, R100.2, U8.8, U8.9 (-)
FILTER_MODE_A: R101.2, U10.11 (A); also elsewhere on the board
FILTER_MODE_B: R102.2, U10.10 (B); also elsewhere on the board
FILTER_MODE_C: R103.2, U10.9 (C); also elsewhere on the board
GND: C35.1, C36.1, C37.1, C38.1, C39.1, C40.1, R65.2, R66.2, R67.2, R68.2, R101.1, R102.1, R103.1, U8.5 (+), U8.12 (+), U9.12 (+), U10.6 (INH), U10.8 (VSS); also elsewhere on the board
unnamed: R65.1, R69.2, U8.2 (-)
unnamed: R66.1, R70.2, U9.2 (-)
unnamed: R67.1, R71.2, U9.9 (-)
unnamed: R68.1, R72.2, U9.6 (-)
unnamed: R69.1, R73.1, U8.1
unnamed: R71.1, R74.1, U9.8
unnamed: R73.2, R75.1, U8.6 (-)
unnamed: R74.2, R76.1, U9.13 (-)
unnamed: R104.1, U8.13 (-), U10.3 (X)
VCA_IN: R104.2, U8.14; also elsewhere on the board
VCF_OUT: U8.10 (+); also elsewhere on the board
X0: R80.1, U10.13 (X0)
X1: R81.1, U10.14 (X1)
X2: R82.1, R83.1, R84.1, R85.1, R86.1, U10.15 (X2)
X3: R87.1, R88.1, R89.1, U10.12 (X3)
X4: R77.1, R78.1, R79.1, U10.1 (X4)
X5: R90.1, R91.1, U10.5 (X5)
X6: R92.1, R93.1, R94.1, R95.1, U10.2 (X6)
X7: R96.1, R97.1, R98.1, R99.1, R100.1, U10.4 (X7)

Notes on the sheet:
2P LP
2P HP
3P AP + 1P LP
4P LP
4P BP
2P BP
4P HP
4P N

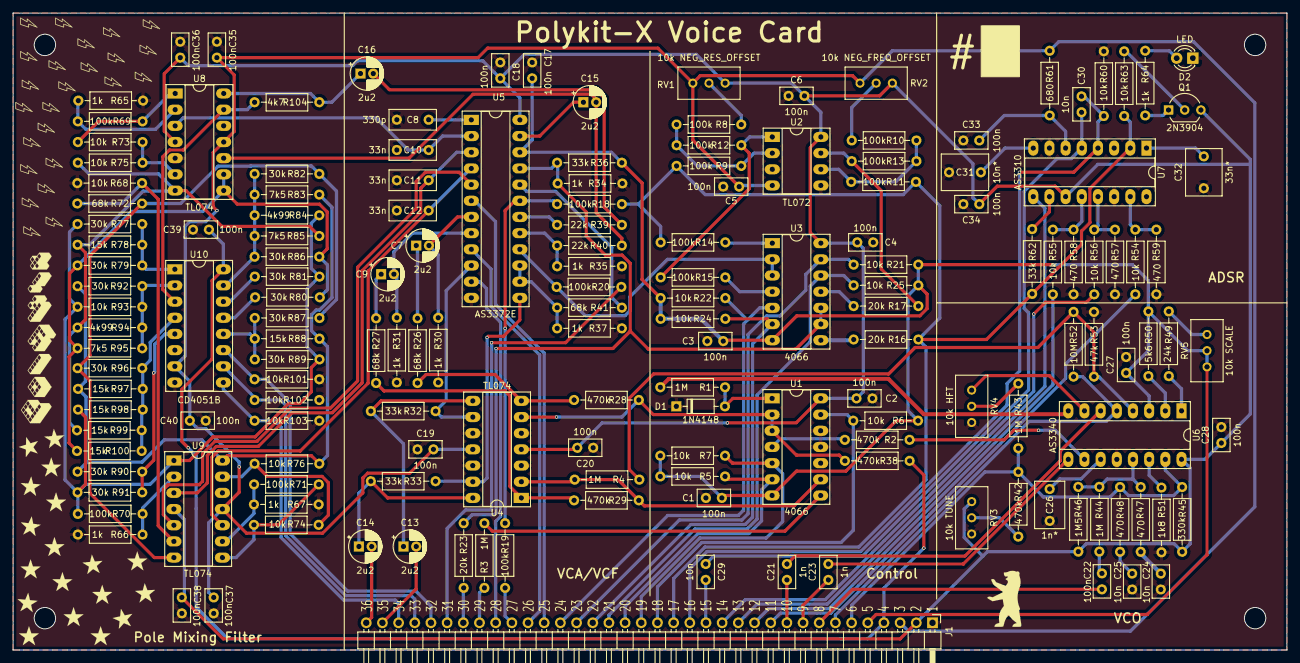
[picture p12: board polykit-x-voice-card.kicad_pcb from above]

Board: 2 copper layers, 200.0 x 100.0 mm, 163 parts (0 on the bottom side), 127 nets.

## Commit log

2022-06-19 Initial import
    [AS3310.kicad_sch, AS3340.kicad_sch, AS3372E.kicad_sch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]
2022-08-23 - add R38 offset to IN1 - change 4016 to 4066
    [AS3310.kicad_sch, AS3340.kicad_sch, AS3372E.kicad_sch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]
2022-12-17 Fix bom
2023-01-26 Bump to v1.0.0
    [AS3310.kicad_sch, AS3340.kicad_sch, AS3372E.kicad_sch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]
2023-02-06 Update pdf schematics
